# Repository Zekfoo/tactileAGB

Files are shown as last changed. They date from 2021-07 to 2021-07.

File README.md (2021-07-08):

# Background

CURRENT VERSION - REV 1.1

This mod for the Game Boy Advance (AGB) was inspired by makho's [AGB_TACT](https://github.com/makhowastaken/AGB_TACT) project which added tactile buttons to the AGB to create a similar clicky feel to the GBA SP and more recent Nintendo handhelds.

Developed from the ground up, this implementation offers a no-wires-required solution, consisting of 3 flex breakout boards for the DPAD, A/B, and START/SELECT.

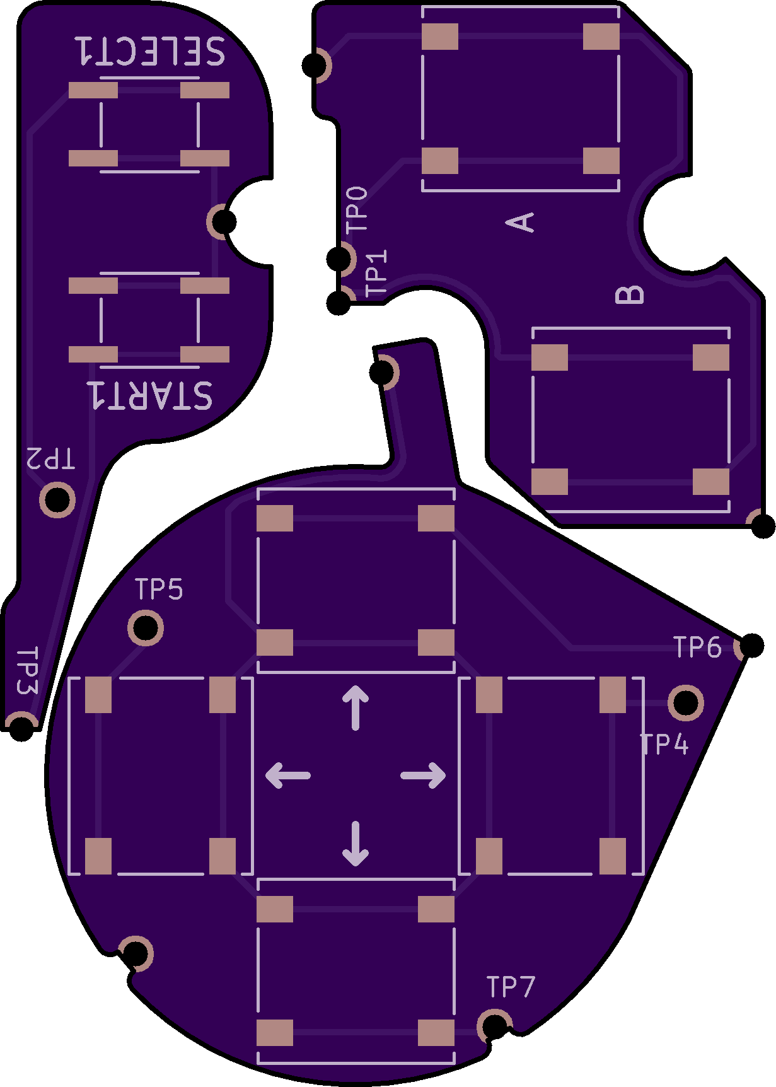
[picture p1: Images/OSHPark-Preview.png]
Preview


# Mod Compatibility

This mod is only compatible with AGB-001. 

Due to variability between OEM and different aftermarket buttons and membranes, some adjustments may need to be made to adjust the button height and travel distances - more details in the Installation section.

Compatibility with the IPS v2 mod's brightness controls is ensured - just solder the SELECT wire overtop of the TP2 hole.

# Board and Parts Links

Flex board order link ($20.70 for 3 sets) - [OSH Park](https://oshpark.com/shared_projects/KdYTs0bl)

SKRRABE010 (for DPAD and A/B - GBA SP Buttons) - [Mouser](https://www.mouser.com/ProductDetail/?qs=m0BA540hBPcAX44PgGtO0w%3D%3D)

SOG-152ANT (for START/SELECT) - [Digikey](https://www.digikey.ca/en/products/detail/mitsumi-electric-company-ltd/SOG-152ANT/11591283)

# Disclaimer

As with all hardware mods, you risk irreparable damage to your device if the proper precautions are not taken. Feel free to reach out for any questions or troubleshooting.

# Installation

**General:**
* Solder SKRRABE010 buttons to their corresponding footprints on the DPAD and A/B flex boards
* Solder SOG-152ANT buttons to their corresponding footprints on the START/SELECT flex board

**DPAD**
* Line up the holes labelled TP4, TP5, and TP7 with the corresponding testpoints on the AGB board, this should align all solder points with their corresponding contacts
* Solder:
  * TP4, TP5, TP6, and TP7 for each of the 4 DPAD buttons
  * Ground connection to the pad of the L button shielding
  * (Optional) VDD-15 can be used as an anchor point

**A/B**
* Line up the holes labelled TP0 and TP1 with the corresponding test points on the AGB board
* Solder:
  * TP0 and TP1 for A and B respectively
  * Ground connection to upper right GND pad
  * (Optional) FR2 can be used as an anchor point

**START/SELECT**
* Line up the holes labelled TP2 and TP3 with the corresponding test points on the AGB board
* Solder:
  * TP2 and TP3 for SELECT and START respectively
  * Ground connection to left GND pad
  * (For IPS v2 brightness controls) Solder the SELECT wire from the IPS ribbon cable overtop of the TP2 hole.

**Button height/travel**
* The button travel distance may need to be adjusted based on individual preference - simply insert some thin cardboard between the tactile buttons and membranes in order to shorten the travel distance 
* Cardboard may also need to be inserted under the center of the DPAD membrane in order to raise its pivot point - a properly functioning DPAD should only be able to register 2 directions at the same time - if you own a flash cart, you can check using this [ROM](https://github.com/heroldev/AGB-buttontest)

# Acknowledgements

Thanks to [makho](https://www.youtube.com/channel/UC5FYpo9lFqK1Y7wqjPuANFw) for his original project idea and video.

Thanks to [HDR](https://martinrefseth.com/) for compiling his Nintenfo repository, which made development much swifter.

# License

<br />This work is licensed under a <a rel="license" href="http://creativecommons.org/licenses/by-nc-sa/4.0/">Creative Commons Attribution-NonCommercial-ShareAlike 4.0 International License</a>.

Feel free to modify this design however you like, but please make sure to give credit where it is due. I encourage you to share your improvements with the rest of the Gameboy modding community at the Gameboy [Discord](https://discord.gg/RYN3bMxr) and [Subreddit](https://www.reddit.com/r/Gameboy/)

Under this license, you are not permitted to profit from or commercialize this design in any part without my express permission.

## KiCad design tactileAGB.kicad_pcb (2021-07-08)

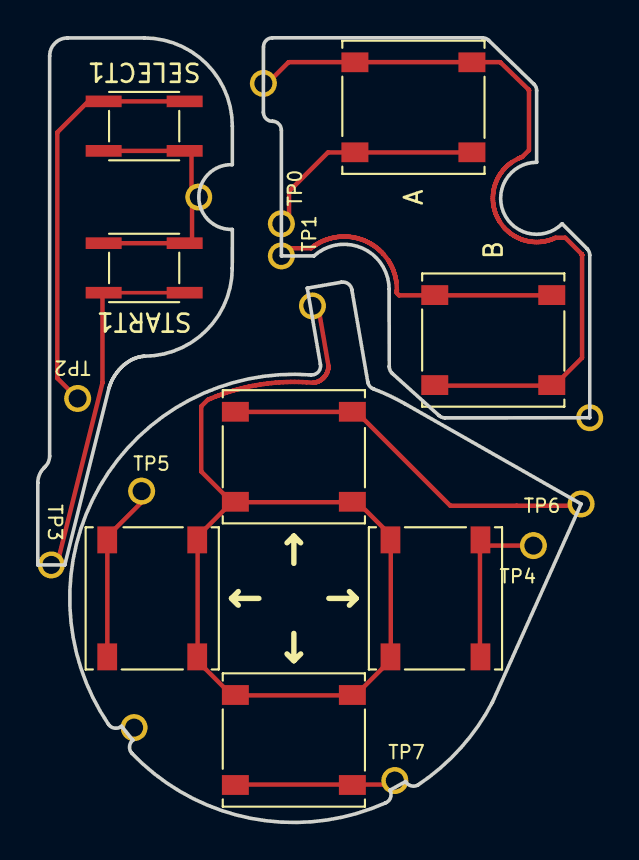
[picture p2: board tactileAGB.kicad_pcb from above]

Board: 2 copper layers, 30.7 x 43.6 mm, 21 parts (0 on the bottom side), 11 nets.

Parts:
A: SKRRABE010
B: SKRRABE010
FR2: TestPoint; Hole-1.5mm
GND2PAD1, GND3PAD1: TestPoint; Hole-1.5mm
L-SHIELDING1: TestPoint; Hole-1.5mm
SELECT1: SOG-152ANT; SOG-15xANT
START1: SOG-152ANT; SOG-15xANT
TP0, TP1, TP2, TP3, TP4, TP5, TP6, TP7: TestPoint; Hole-1.5mm
VDD-15: TestPoint; Hole-1.5mm
↑: SKRRABE010
↑#2, ↑#3, ↑#4: SKRRABE010

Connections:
GND1: L-SHIELDING1.1, ↑.3, ↑.4, ↑#2.3, ↑#2.4, ↑#3.3, ↑#3.4, ↑#4.3, ↑#4.4
GND2: GND2PAD1.1, SELECT1.3, SELECT1.4, START1.3, START1.4
GND3: A.3, A.4, B.3, B.4, GND3PAD1.1
unnamed: A.1, A.2, TP0.1
unnamed: B.1, B.2, TP1.1
unnamed: TP7.1, ↑.1, ↑.2
unnamed: TP5.1, ↑#2.1, ↑#2.2
unnamed: TP4.1, ↑#3.1, ↑#3.2
unnamed: SELECT1.1, SELECT1.2, TP2.1
unnamed: START1.1, START1.2, TP3.1
unnamed: TP6.1, ↑#4.1, ↑#4.2

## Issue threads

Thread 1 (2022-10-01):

Do not recommend this mod?

iVirtualPlays, 2022-10-01:
I attempted to install this mod but could not get it to fit, almost damaged my GBA. It’s too thick and puts lot of pressure and flex on the motherboard pcb, also the button will not click right at times. It has to almost be perfectly lined up to get the right click. I recommend getting an SP if you want clicky buttons. Overall membranes are better for long term reliability, no soldering necessary to get them working compared to tactile.

Zekfoo, 2022-10-01:
Thickness shouldn't be an issue if you've ordered the boards as flex PCBs as stated in the description.
As with all hardware mods, you run the risk of damage to your devices if not handled properly.

Closed 2022-10-01.

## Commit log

2021-06-21 Initial commit - rev 1.0
    [tactileAGB-B_Cu.gbl, tactileAGB-B_Mask.gbs, tactileAGB-B_Paste.gbp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]
2021-06-21 Fixed naming of testpoint VDD-15
    [tactileAGB.kicad_pcb, tactileAGB.sch]
2021-06-21 Reduced gerber size to lower OSH Park cost
    [tactileAGB-B_Cu.gbl, tactileAGB-B_Mask.gbs, tactileAGB-B_Paste.gbp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]
2021-07-08 Rev 1.1 - changed to GBA SP buttons, removed NoStartSelect gerber option
    [tactileAGB-B_Cu.gbl, tactileAGB-B_Mask.gbs, tactileAGB-B_Paste.gbp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]
2021-07-08 Updated PCB preview for rev 1.1
